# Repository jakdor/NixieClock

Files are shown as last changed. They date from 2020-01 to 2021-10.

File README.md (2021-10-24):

# Nixie clock firmware
### Firmware for IN12/IN14 nixie clock ATmega8 based design

For other PCB design checkout current branch:

| Design name | GIT branch |
| --- |:---:|
| IN-12 (THT) | IN12THT |
| IN-12 (SMD) | IN12SMD |
| IN-14 (SMD) | IN14SMD |

Compiling project
------

#### Windows

Download latest Atmel Studio IDE [Atmel Studio 7](https://www.microchip.com/mplab/avr-support/atmel-studio-7)

#### GNU/Linux (tested on Debian)

Makefile is located in Firmware/GccApplication2/ folder.

install dependencies:

```
make install
```

compile project:

```
make
```

flash ATmega using USBasp programmer:

```
make flash
```

PCB project
------

[PCB IN-12 Nixie clock](https://circuitmaker.com/Projects/Details/Jakub-Dorda/IN-12-Nixie-clock)

Output gerber files are located in 'PCBgerber' folder.

Compiled firmware
------

Download latest compiled firmware from GitHub repository release tab:

[Latest release](https://github.com/jakdor/NixieClock/releases)

Documentation/manuals
------

Documentation is located in 'Docs' folder or under this link:

[ASSEMBLY GUIDE/USER MANUAL/PARTS LIST](https://drive.google.com/drive/folders/0B9FzEUmQ64ufNGhZc0ZZaVdwLUU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)

FEATURES
------
* Full RGB backlight!
* Compact design
* HH:MM:SS format
* 24/12 h display format
* Alarm clock
* Backup power and settings memory
* Maintains time after power loss
* Backup battery lifetime up to 20 years
* accurate Real Time Clock
* Roulette Effect every hour (prevents cathode poisoning)
* Simple 3-buttons interface
* manual nixie brightness
* 3 separator modes (on, off, blinking)
* 6 RGB backlight modes including user defined and off
* night mode (turning off nixies and backlight between user set hours)

------

YouTube videos:

[https://www.youtube.com/watch?v=hwEY1RJ39X0](https://www.youtube.com/watch?v=hwEY1RJ39X0)

[https://www.youtube.com/watch?v=vacfdvKtQjE](https://www.youtube.com/watch?v=hwEY1RJ39X0)

NixieClock

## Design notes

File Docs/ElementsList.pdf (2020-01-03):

Designator | Value | Symbol | Quantity | Comment
Y1 | 32.768KHZ | - | 1
Y0 | 8Mhz | - | 1
X6-X9 | nixie IN-3 | - | 4 | or similar, can be modern neon
X0-X5 | nixie IN-12B | - | 6
VR0 | LM7805 | - | 1 | or similar 5V 1A linear stabilizer
U3 | K155NA1/SN74141N | - | 1 | available on eBay
U2 | NE555P | - | 1
U1 | DS1307 | - | 1
U0 | ATmega8A-PU | - | 1 | included with PCB
SW0-SW2 | 6mm switch | - | 3 | angular
R64-R69 | 15k | ████ | 6
R60-R63, R20 | 220k | ████ | 5
R42-R59 | 220 SMD 0805 | 220 | 18 | pre-soldered, value for 3000mcd LEDs
R35-R41 | 100k | ████ | 7
R28-R34 | 470k | ████ | 7
R18, R21-R27 | 33k | ████ | 8
R4-R6, R19 | 470 | ████ | 4
R1-R3, R15-R17 | 1k | ████ | 6
R0, R8-R14 | 10k | ████ | 8
Q14-Q20 | MPSA92 | - | 7 | or other PNP -300V -0.5A
Q7-Q13 | MPSA42 | - | 7 | or other NPN 300V 0.5A
Q6 | BC547BG | - | 1
Q5 | IRF730 | - | 1 | or other N-channel mosfet 2A
Q4 | 2N2907A | - | 1
Q1-Q3 | 2N3904TF | - | 3
P0 | 1k potentiometer | - | 1
L0 | 100uH | - | 1
J0 | 2.1/5.5mm 9v DC | - | 1
D3-D8 | LED 5mm RGB c. cathode | - | 6 | recommended min 3000mcd
D1 | UF4007 | - | 1 | super-fast <75ns 400V 1A
D0, D2 | 1N4007 | - | 2 | Rectifier diode 400V 1A
C16 | 2.2uF 400v | - | 1
C15 | 47pF | 47 | 1
C14 | 470uF | - | 1
C13 | 2.2nF | 222 | 1
C7-C8 | 22pF | 22 | 2
C2, C4-C6, C12 | 100nF | 104 | 5
C0, C1, C3 | 100uF | - | 3
BT0 | coincell CR2032 holder | - | 1
B0 | Buzzer Piezo 5v | - | 1 | with generator
Connector | M20 Vertical Pin Header | - | 21
Socket | Nixie pins | - | 72 | available on eBay

## Nixie pins can be skipped if you don't mount backlight LEDs

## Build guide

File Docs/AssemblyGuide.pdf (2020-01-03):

# ASSEMBLY GUIDE

# IN-12 NIXIE CLOCK v1.1

### Jakub Dorda © 2016-2017

2 | IN-12 Nixie Clock

### What You will need:

| • Soldering iron with standard and precise tip
- Side cutters
- Solder
| • Solder pump or solder wick (for correcting mistakes)

### Optional:

| • Pliers / small tongs / twisters
- Crocodile clip
- Multimeter

Estimated assembly time: 7-9h

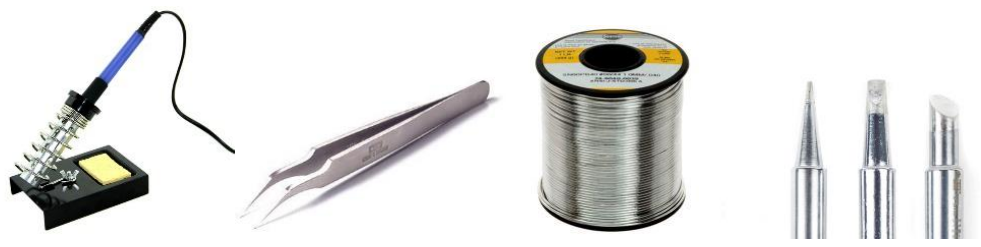
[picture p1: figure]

### Table of elements

Designator | Value | Symbol | Quantity
Y1 | 32.768KHZ | - | 1
Y0 | 8Mhz | - | 1
X6-X9 | nixie IN-3 | - | 4
X0-X5 | nixie IN-12B | - | 6
VR0 | LM7805 | - | 1
U3 | K155NA1/SN74141N | - | 1
U2 | NE555P | - | 1
U1 | DS1307 | - | 1

jak_dor | IN-12 Nixie Clock | 3
U0 | ATmega8A-PU | - | 1
SW0-SW2 | 6mm switch | - | 3
R64-R69 | 15k | ████ | 6
R60-R63, R20 | 220k | ████ | 5
R42-R59 | 220 SMD0805 | 220 | 18
R35-R41 | 100k | ████ | 7
R28-R34 | 470k | ████ | 7
R18, R21-R27 | 33k | ████ | 8
R4-R7, R19 | 470 | ████ | 5
R1-R3, R15-R17 | 1k | ████ | 6
R0, R8-R14 | 10k | ████ | 8
Q14-Q20 | MPSA92 | KSP 92 | 7
Q7-Q13 | MPSA42 | A 42 | 7
Q6 | BC547BG | - | 1
Q5 | IRF730 | - | 1
Q4 | 2N2907A | - | 1
Q0-Q3 | 2N3904TF | - | 4
P0 | 1k potentiometer | - | 1
L0 | 100uH | - | 1
J0 | 2.1/5.5mm 9v DC | - | 1
D3-D8 | LED 5mm RGB | - | 6
D1 | UF4007 | - | 1
D0, D2 | 1N4007 | - | 2
C16 | 2.2uF | - | 1
C15 | 47pF | 47 | 1
C14 | 470uF | - | 1
C13 | 2.2nF | 222 | 1
C7-C8 | 22pF | 22 | 2
C2, C4-C6, C12 | 100nF | 104 | 5
C0, C1, C3 | 100uF | - | 3
BT0 | coincell CR2032 holder | - | 1
B0 | Buzzer Piezo 5v | - | 1
Connector | M20 Vertical Pin Header | - | 21

### 1. SMD elements

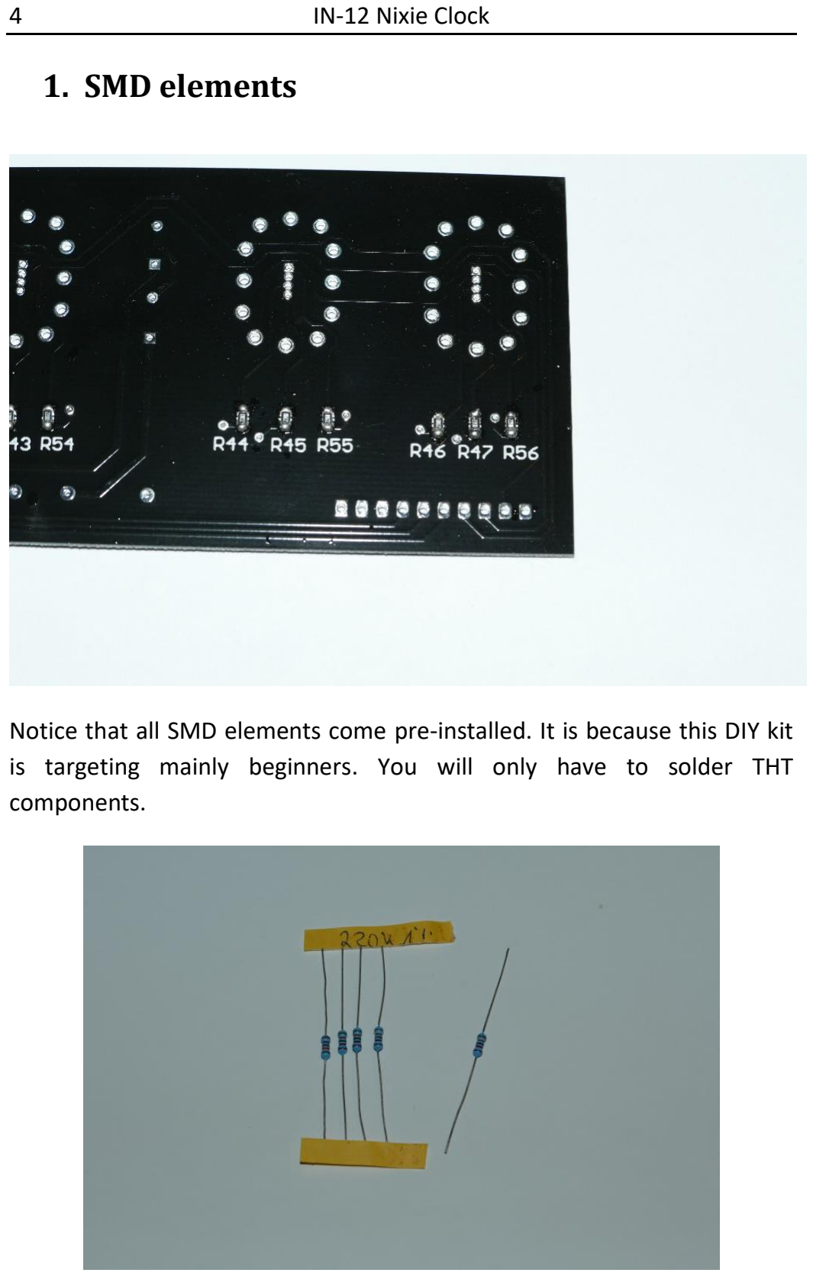
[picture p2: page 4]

Notice that all SMD elements come pre-installed. It is because this DIY kit is targeting mainly beginners. You will only have to solder THT components.

### 2. Resistors

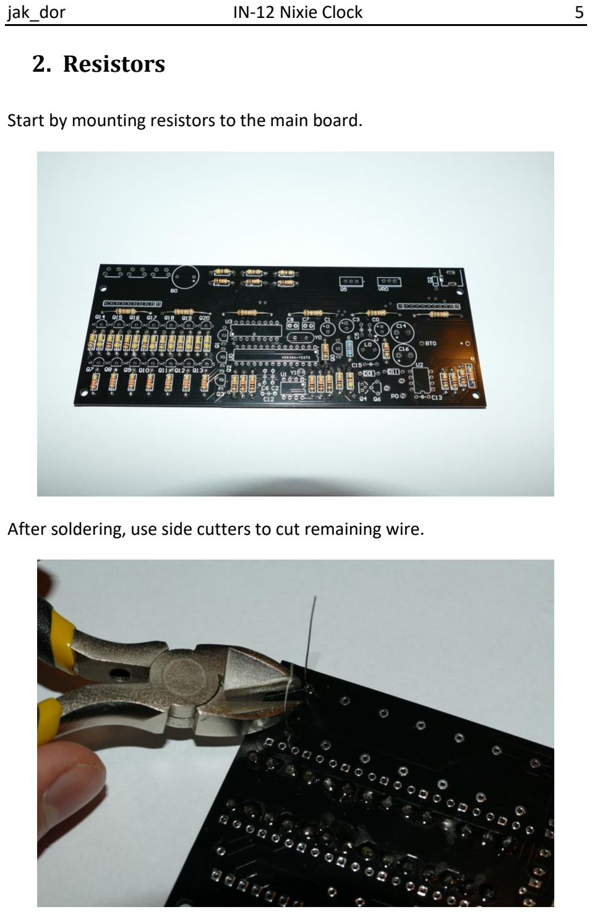
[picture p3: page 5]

Start by mounting resistors to the main board.

After soldering, use side cutters to cut remaining wire.

### 3. Rectifier diodes

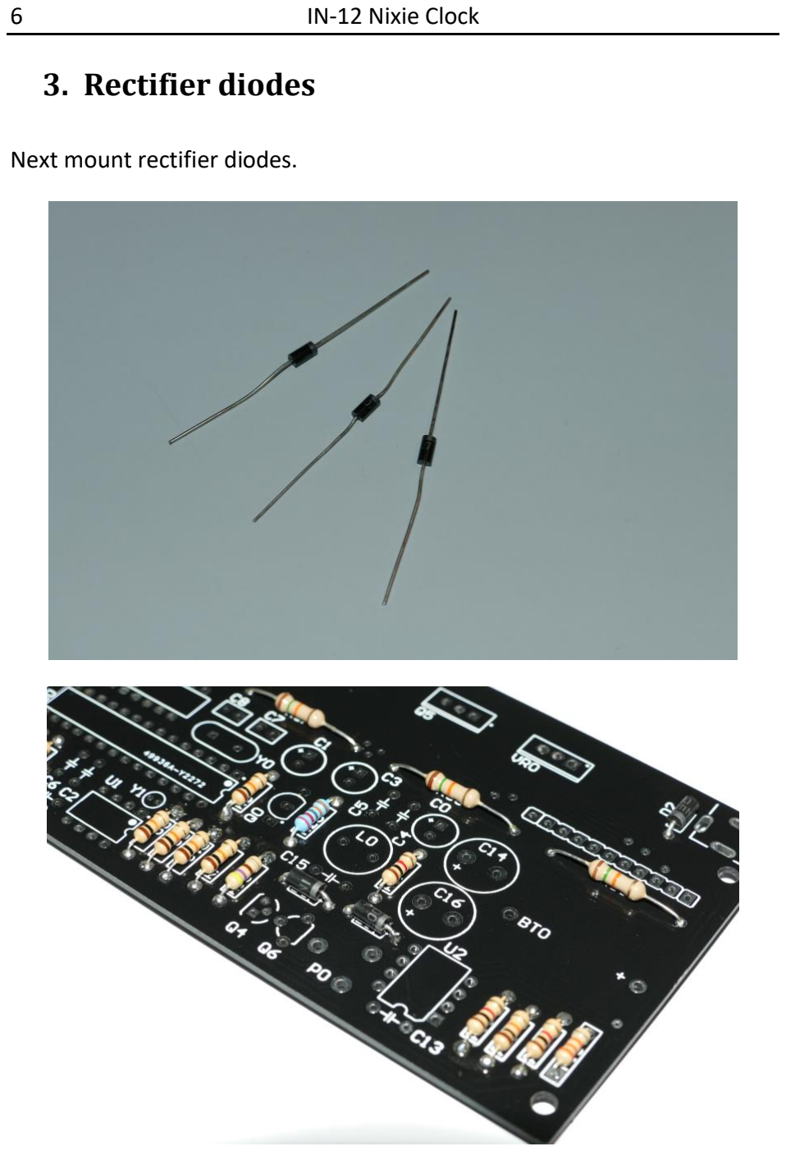
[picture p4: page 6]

Next mount rectifier diodes.

### 4. Integrated circuits sockets

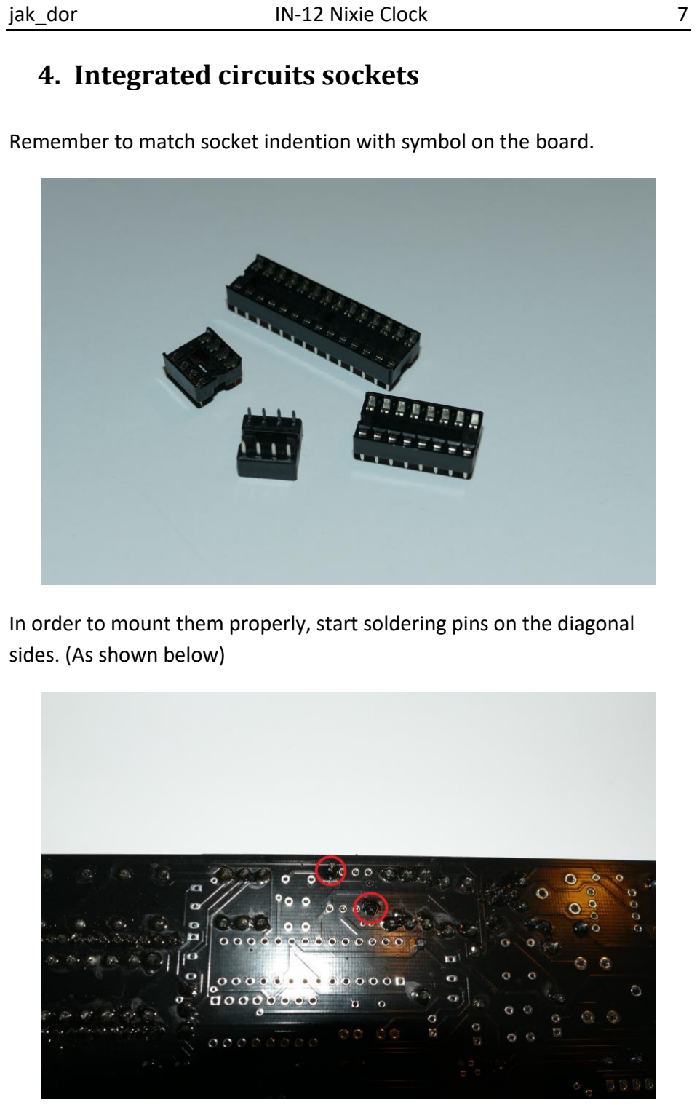
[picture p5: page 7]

Remember to match socket indention with symbol on the board.

In order to mount them properly, start soldering pins on the diagonal sides. (As shown below)

### 5. Transistors

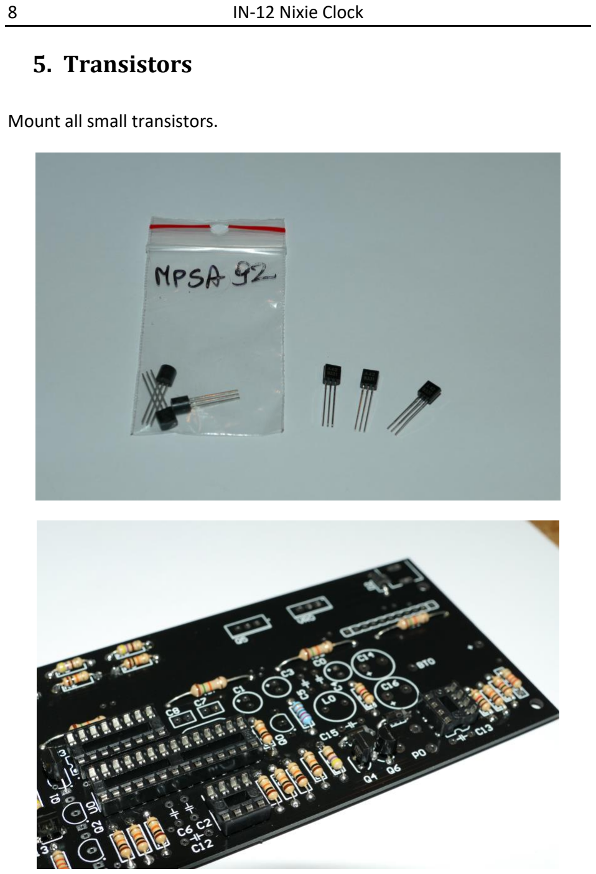
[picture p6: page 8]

Mount all small transistors.

### 6. Ceramic capacitors

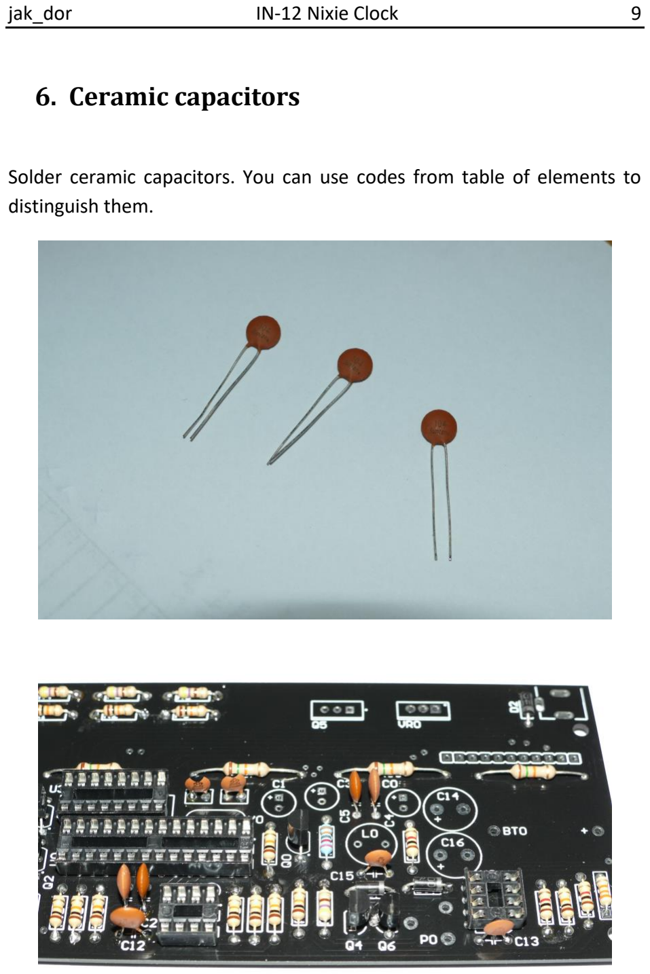
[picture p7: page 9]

Solder ceramic capacitors. You can use codes from table of elements to distinguish them.

### 7. Crystals

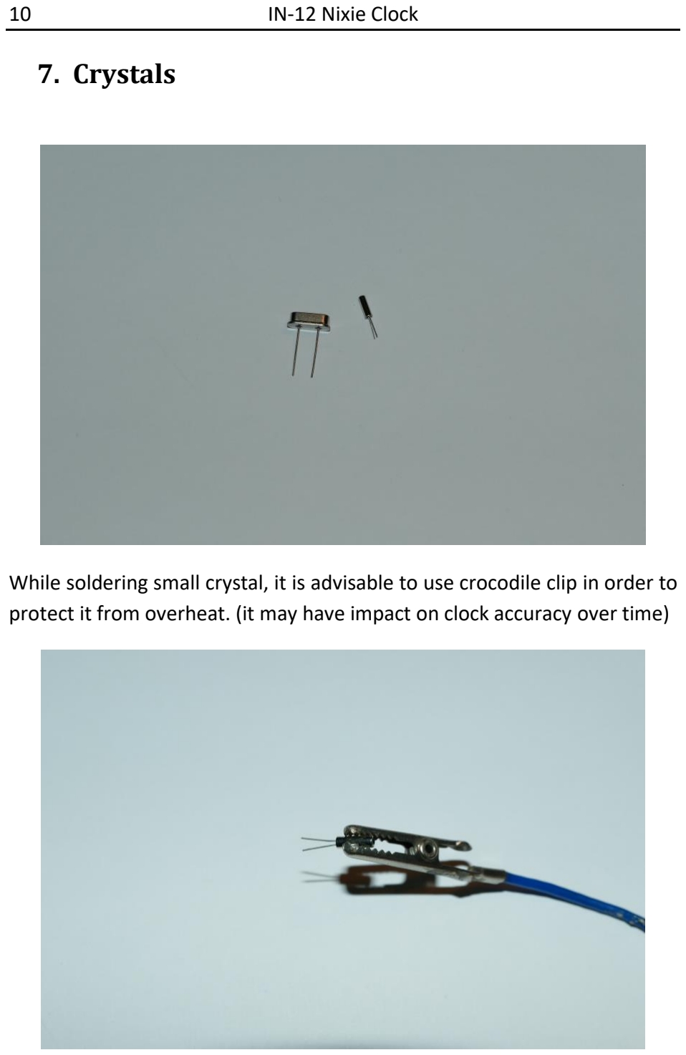
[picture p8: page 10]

While soldering small crystal, it is advisable to use crocodile clip in order to protect it from overheat. (it may have impact on clock accuracy over time)

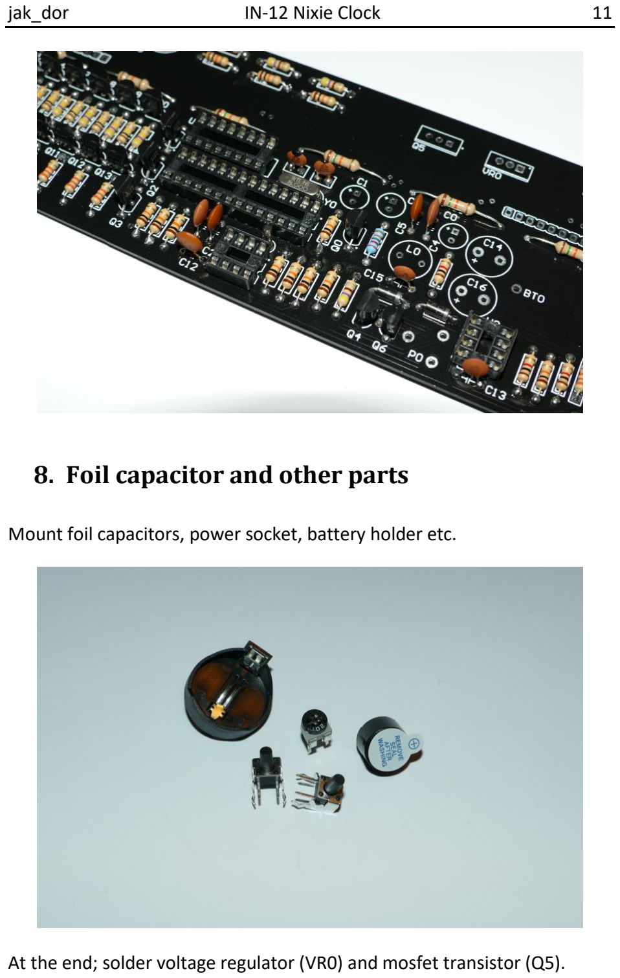
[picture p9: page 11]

### 8. Foil capacitor and other parts

Mount foil capacitors, power socket, battery holder etc.

At the end; solder voltage regulator (VR0) and mosfet transistor (Q5).

### 9. Miscellaneous elements on the display board

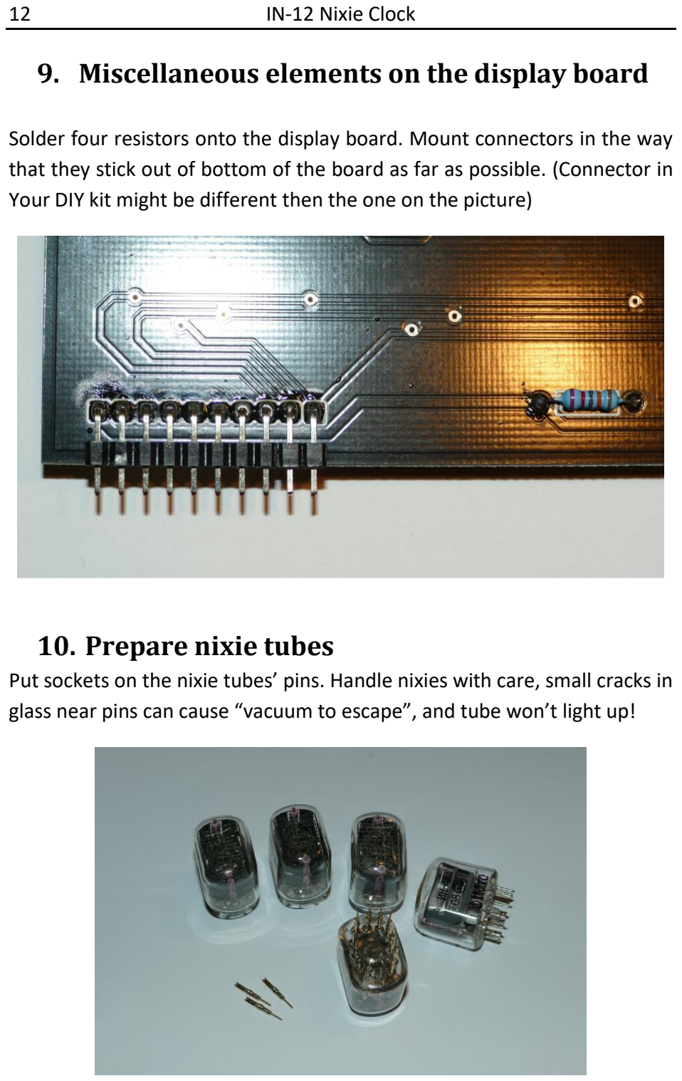
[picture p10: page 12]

Solder four resistors onto the display board. Mount connectors in the way that they stick out of bottom of the board as far as possible. (Connector in Your DIY kit might be different then the one on the picture)

### 10. Prepare nixie tubes

Put sockets on the nixie tubes’ pins. Handle nixies with care, small cracks in glass near pins can cause “vacuum to escape”, and tube won’t light up!

### 11. Solder nixie tubes’ sockets

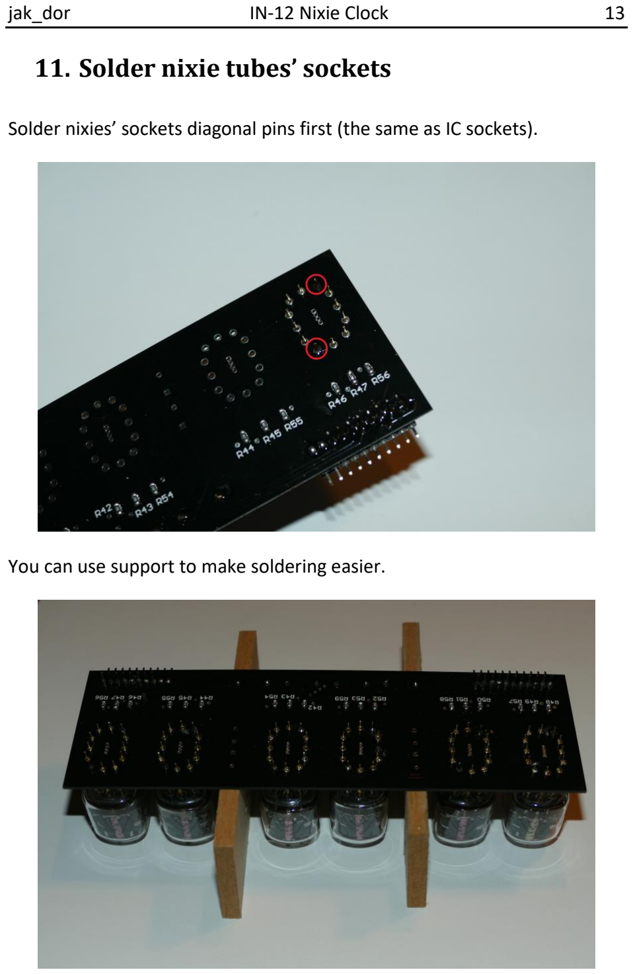
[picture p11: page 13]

Solder nixies’ sockets diagonal pins first (the same as IC sockets).

You can use support to make soldering easier.

### 12. Remove nixies from sockets

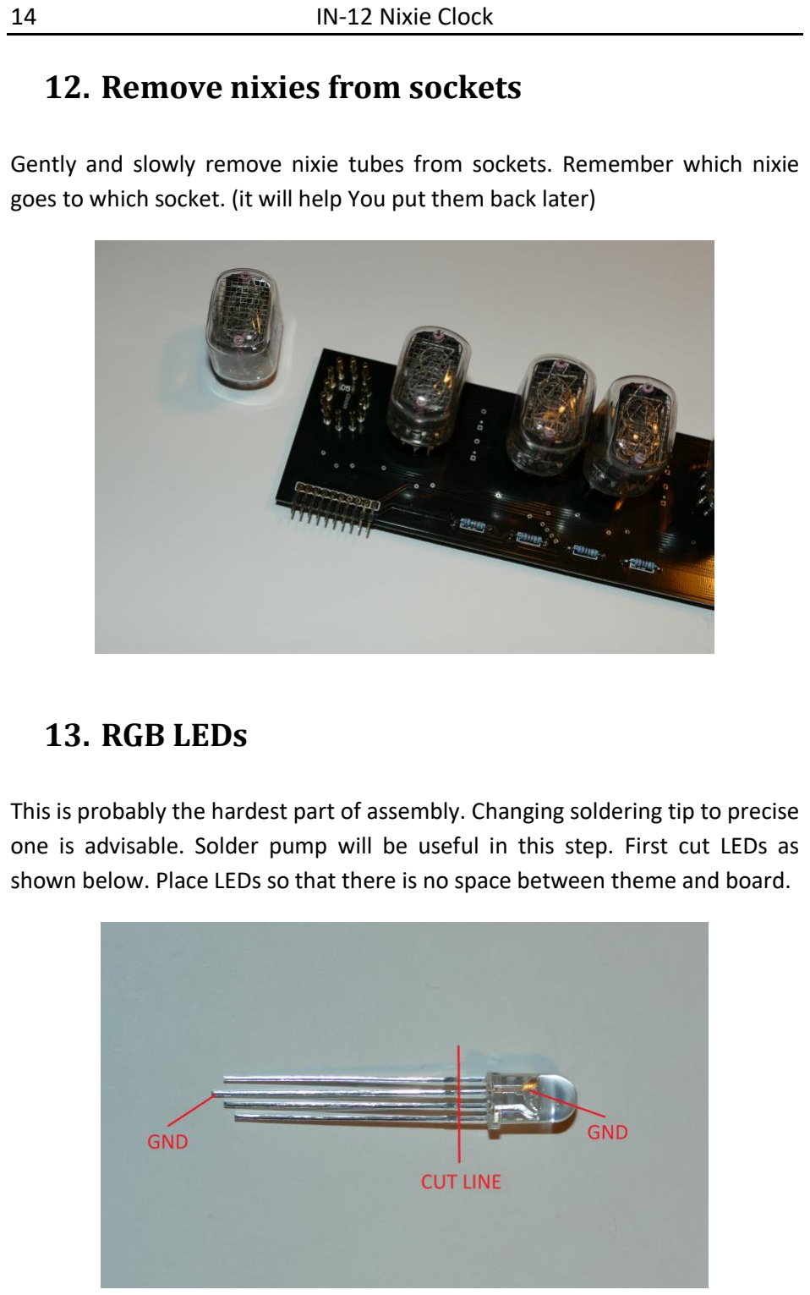
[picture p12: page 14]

Gently and slowly remove nixie tubes from sockets. Remember which nixie goes to which socket. (it will help You put them back later)

### 13. RGB LEDs

This is probably the hardest part of assembly. Changing soldering tip to precise one is advisable. Solder pump will be useful in this step. First cut LEDs as shown below. Place LEDs so that there is no space between theme and board.

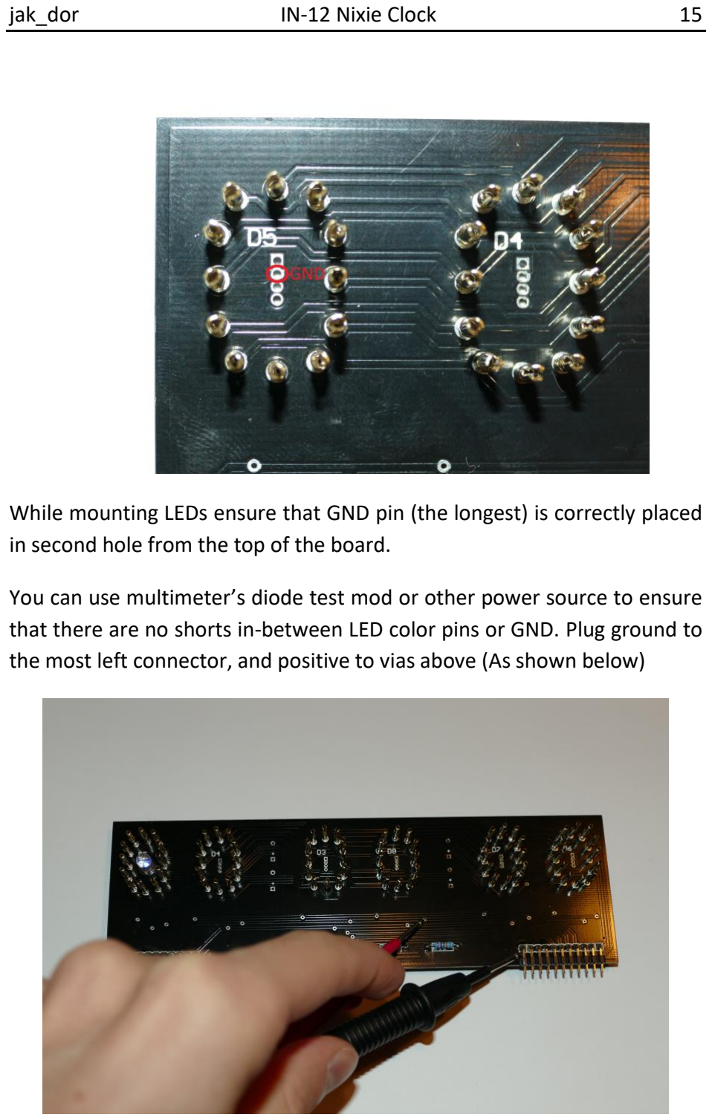
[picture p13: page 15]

While mounting LEDs ensure that GND pin (the longest) is correctly placed in second hole from the top of the board.

You can use multimeter’s diode test mod or other power source to ensure that there are no shorts in-between LED color pins or GND. Plug ground to the most left connector, and positive to vias above (As shown below)

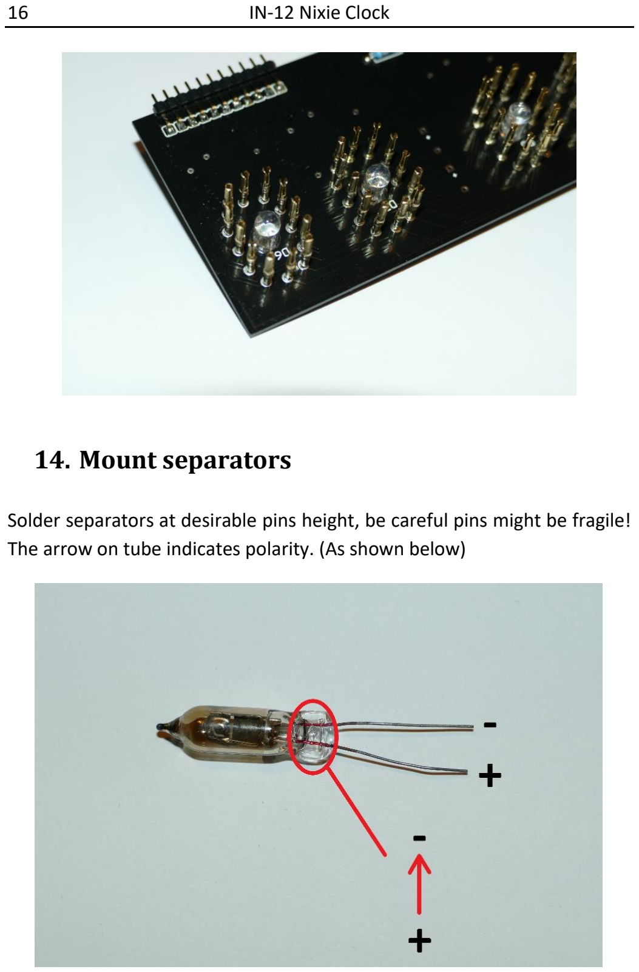
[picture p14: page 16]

### 14. Mount separators

Solder separators at desirable pins height, be careful pins might be fragile! The arrow on tube indicates polarity. (As shown below)

### 15. Place nixie tubes back in their sockets

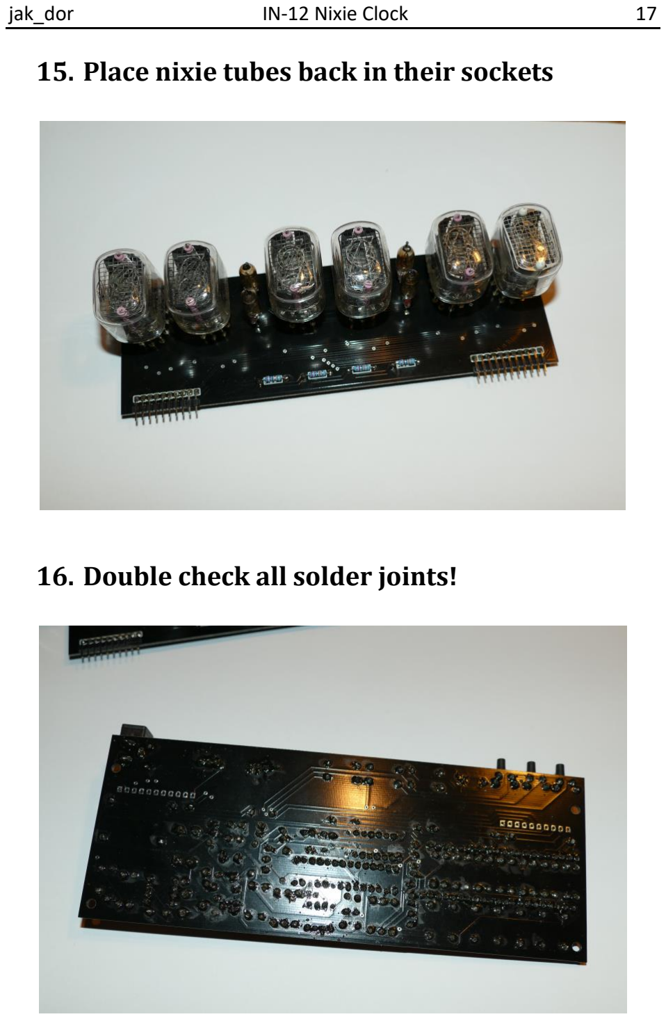
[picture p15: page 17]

### 16. Double check all solder joints!

### 17. Place IC in their sockets

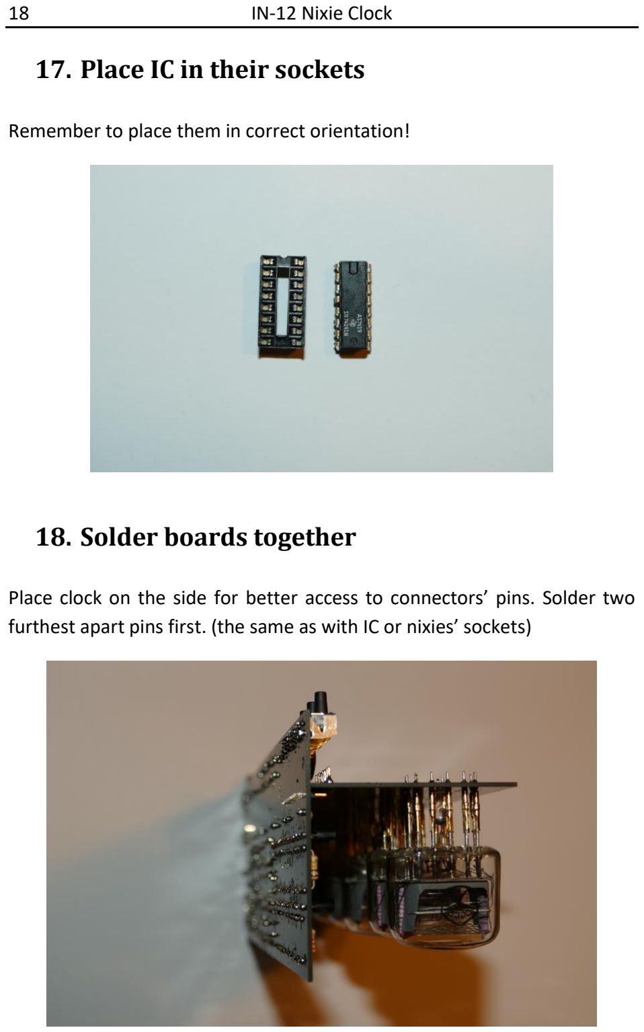
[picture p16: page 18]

Remember to place them in correct orientation!

### 18. Solder boards together

Place clock on the side for better access to connectors’ pins. Solder two furthest apart pins first. (the same as with IC or nixies’ sockets)

### 19. Turn on

After last step, the clock should be completed. Just insert battery (will not boot up without it!), plug the power supply and You are ready to go!

Don’t forget to set up time first and adjust brightness. You will find instruction how to do that in the User Manual.

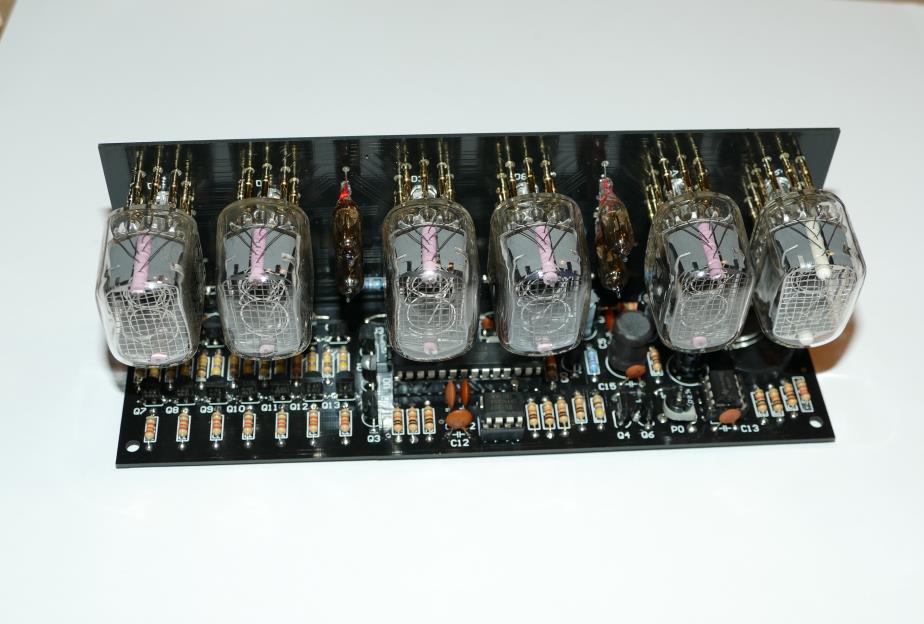
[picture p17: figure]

I hope everything went as planned, and Your nixie clock is working flawlessly and it will serve You for many years to come!

Sincerely, Jakub Dorda

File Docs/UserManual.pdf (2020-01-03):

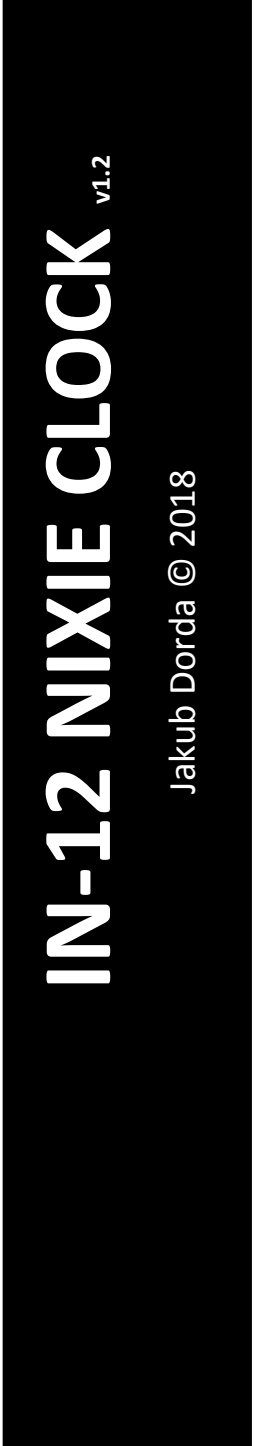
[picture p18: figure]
IN-12 NIXIE CLOCK v1.2; Jakub Dorda © 2018

# USER MANUAL

2 | IN-12 Nixie Clock

## Table of contents

jak_dor | IN-12 Nixie Clock | 3

### Introduction

Thank You for choosing this nixie clock, I sincerely hope that owning and using it will give You as much fun and satisfaction as designing it gave me. If You have any questions or encountered unpredicted problem; contact me through this e-mail address: jak_dor@wp.pl or eBay message.

| | Sincerely, Jakub Dorda

### High voltage warning

Nixie tubes require high voltage to operate, therefore this nixie clock has some parts of its circuitry that run voltage around 180-300V DC. Do not touch any electric circuit during operation!

### Power supply

This device requires 9V DC constant voltage power source with at least 400mA load capability. Power plug must have 2.1/5.5 standard with center positive polarity; (-) outside barrel (+) inside tip. It is advisable to use good quality stabilized or pulse power based supply.

### First use

Insert DC power plug first then plug power supply into electrical outlet. Clock should start operating right away. If display is showing 00:00:80 it is sign that time was never set or backup battery was replaced. In order to fix it look up how to set up time (page 5).

## Settings and usage

Buttons description
Buttons are named by their position while looking at the clock from the front
Left | – down / change display format
Middle | – settings / next field
Right | – up / alarm on & off

Changing display format
While clock is displaying time, press | Left | button to switch between 12h and
24h display format.

Alarm on & off
While clock is displaying time, press Right button to turn alarm on and off. Setting alarm on is indicated by three beeps. Setting alarm off is indicated by one beep lasting 2 seconds.

Settings’ mode

In order to enter settings’ mode, click Middle. First two digits represents menu page and next four nixies displays values in two fields that you can modify. Field that you are currently modifying will blink.

If you press | Right | while first two digits blink, you will move forward to next
setting page. By pressing | Middle, you can change active field to the next
one, and modify it with Right and Left buttons.
After moving through all three fields next press of | Middle | button will save
changes and return to normal operation mode.

## Setting pages’ description

### 1. Time setting

First page in settings’ mode allows for modifying current time which clock will display. Notice that although clock has 12/24h display format in order to avoid confusion settings’ mode uses 24h display format only! Sorry for inconvenience.

### 2. Alarm setting

This page allows to set alarm time. After changing value in this page alarm clock is automatically turned on. (How to turn alarm on and off on page 4)

### 3. Night mode start

Night mode allows to turn off nixies and backlight on set time. This allows for increased nixies life span and turning off light source If you sleep in the same room where clock is placed.

During night mode, you can still enter settings’ mode, however setting pages 5 and 6 are not available.

### 4. Night mode end

Setts time after which clock will turn nixies and backlight back on after night mode.

If you don’t want to use night mode set both night mode start and end to the same time. For instance; set both to 00:00.

### 5. Separator and backlight settings

First field allows to modify separators behavior:

0 – turned off
1 – blinking
2 – constantly on

Second field modify backlight behavior:

0 – turned off
1 – changing random RGB color (every 1.5min)
2 – changing base color (red, green, blue) (every 1.5min) 3 – changing random RGB color (every 1h)
4 – changing base color (red, green, blue) (every 1h)
5 – user defined color

Setting 5 without specifying your own color at setting page 6 will save currently displayed color.

### 6. User defined RGB color

This page unlike rest of them doesn’t have first field dedicated to displaying setting page. All three fields represent each base color (red, green, blue). As you modify values backlight will change accordingly. Any change in this page will result in setting mode 5 in backlight behavior automatically.

### Setting nixies’ brightness

First unplug power supply from electrical outlet. Use small slotted or philips screwdriver and gently turn trim pod located in front right part of main board. Turn clock back on to check on results, repeat process until you are satisfied with nixies’ brightness.

### Increasing nixies’ life span

It is advisable not to set brightness too high as it may cause nixies to age faster. Using night mode for couple hours every day will help as well. Don’t forget that clock has backup power so if you are away from home for longer than a day, feel free to turn it off, all settings and time will be saved.

### Anticathode poisoning

Cathode poisoning is happening when nixie tube is turned too long on same digit, therefore setting separators on setting 2 (constantly on) is not advisable.

This clock also has special system that prevents cathode poisoning by “roulette effect” which is happening every hour for 10 seconds.

### Replacing nixie tube

If one of nixie tubes happens to break down or cathode poisoning becomes to apparent, it is probably sign that you should replace it with “new” one.

First unplug power supply, hold display board with one hand, as you gently wobble nixie tube up and down while pulling it towards you. Be careful not to damage sockets. After removing faulty nixie, proceed by inserting new one again by wobbling it carefully as you push it in.

### Troubleshooting

### Clock doesn’t turn on after assembly

If you bought this clock as DIY kit, and it’s not working at all, double check that you didn’t make any mistake during assembly or insert backup battery.

Clock doesn’t turn on but it was working already
Check if clock is not in night mode by pressing Middle. Check if power supply is working correctly.

Clock display acting weirdly
It might be sign that nixie driver (IN74141 or K155ID1) broke down, replace it with new one.

Contact: jak_dor@wp.pl or eBay message

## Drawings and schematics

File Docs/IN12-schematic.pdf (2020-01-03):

1

2

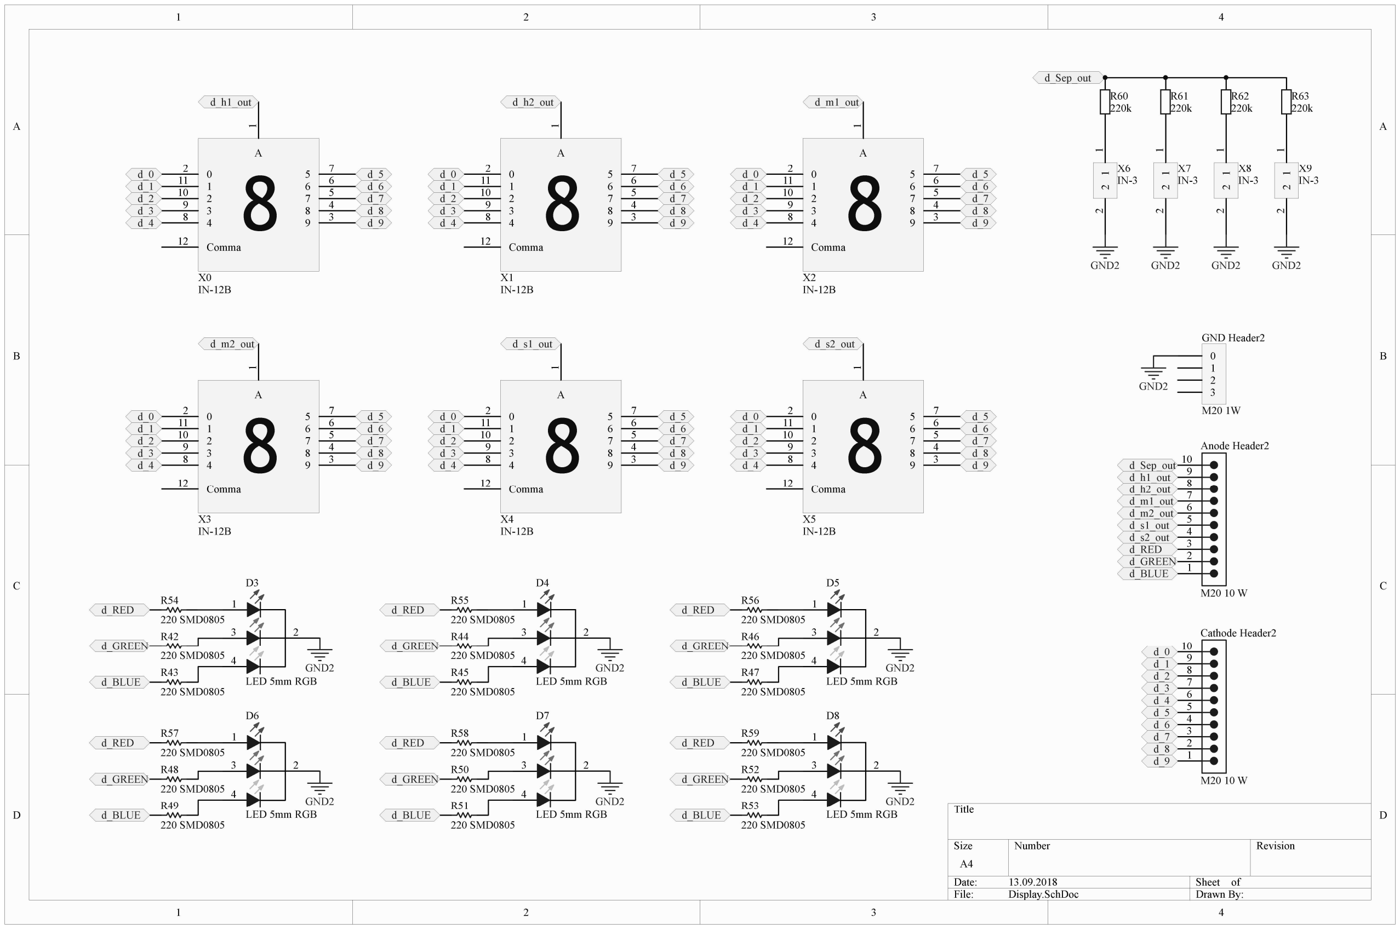
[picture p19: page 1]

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
### Title

Size | Number | Revision
A4
Date: | 13.09.2018 | Sheet of
File: | Display.SchDoc | Drawn By:

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
10 1

11

Comma 12 | 8

X5

### IN-12B

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
10 1

11

Comma 12 | 8

X1

### IN-12B

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
10 1

11

Comma 12 | 8

X3

### IN-12B

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
10 1

11

Comma 12 | 8

X4

### IN-12B

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
10 1

11

Comma 12 | 8

X0

### IN-12B

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
10 1

11

Comma 12 | 8

X2

### IN-12B

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
### Cathode Header2

M20 10 W

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
### Anode Header2

M20 10 W

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
### d_Sep_out d_h1_out d_h2_out d_m1_out d_m2_out d_s1_out d_s2_out

d_h1_out | d_h2_out | d_m1_out
d_m2_out | d_s1_out | d_s2_out

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
### 220 SMD0805

0
1
2
3

### GND Header2

M20 1W

### d_RED d_GREEN d_BLUE

R54

### 220 SMD0805

R42

### 220 SMD0805

1

3

4

2

D3

### LED 5mm RGB

### GND2

### d_RED

### d_GREEN

### d_BLUE

R45

### 220 SMD0805

R55

### 220 SMD0805

R44

### 220 SMD0805

1

3

4

2

D4

### LED 5mm RGB

GND2 | R47
| 220 SMD0805

R56

### 220 SMD0805

R46

### 220 SMD0805

1

3

4

2

D5

### LED 5mm RGB

### GND2

R49

### 220 SMD0805

R57

### 220 SMD0805

R48

### 220 SMD0805

1

3

4

2

D6

### LED 5mm RGB

GND2 | R51
| 220 SMD0805

R58

### 220 SMD0805

R50

### 220 SMD0805

1

3

4

2

D7

### LED 5mm RGB

GND2 | R53
| 220 SMD0805

R59

### 220 SMD0805

R52

### 220 SMD0805

1

3

4

2

D8

### LED 5mm RGB

### GND2

1

1

2

2

X6
IN-3 | 1
| 1

2

2

X7
IN-3 | 1
| 1

2

2

X8
IN-3 | 1
| 1

2

2

X9
IN-3

R60
220k

R61
220k

R62
220k

R63
220k

### d_Sep_out

### d_RED

### d_GREEN

### d_BLUE

### d_RED

### d_GREEN

### d_BLUE

### d_RED

### d_GREEN

### d_BLUE

### d_RED

### d_GREEN

### d_BLUE

### d_RED

### d_GREEN

### d_BLUE

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
### GND2

GND2 | GND2 | GND2 | GND2

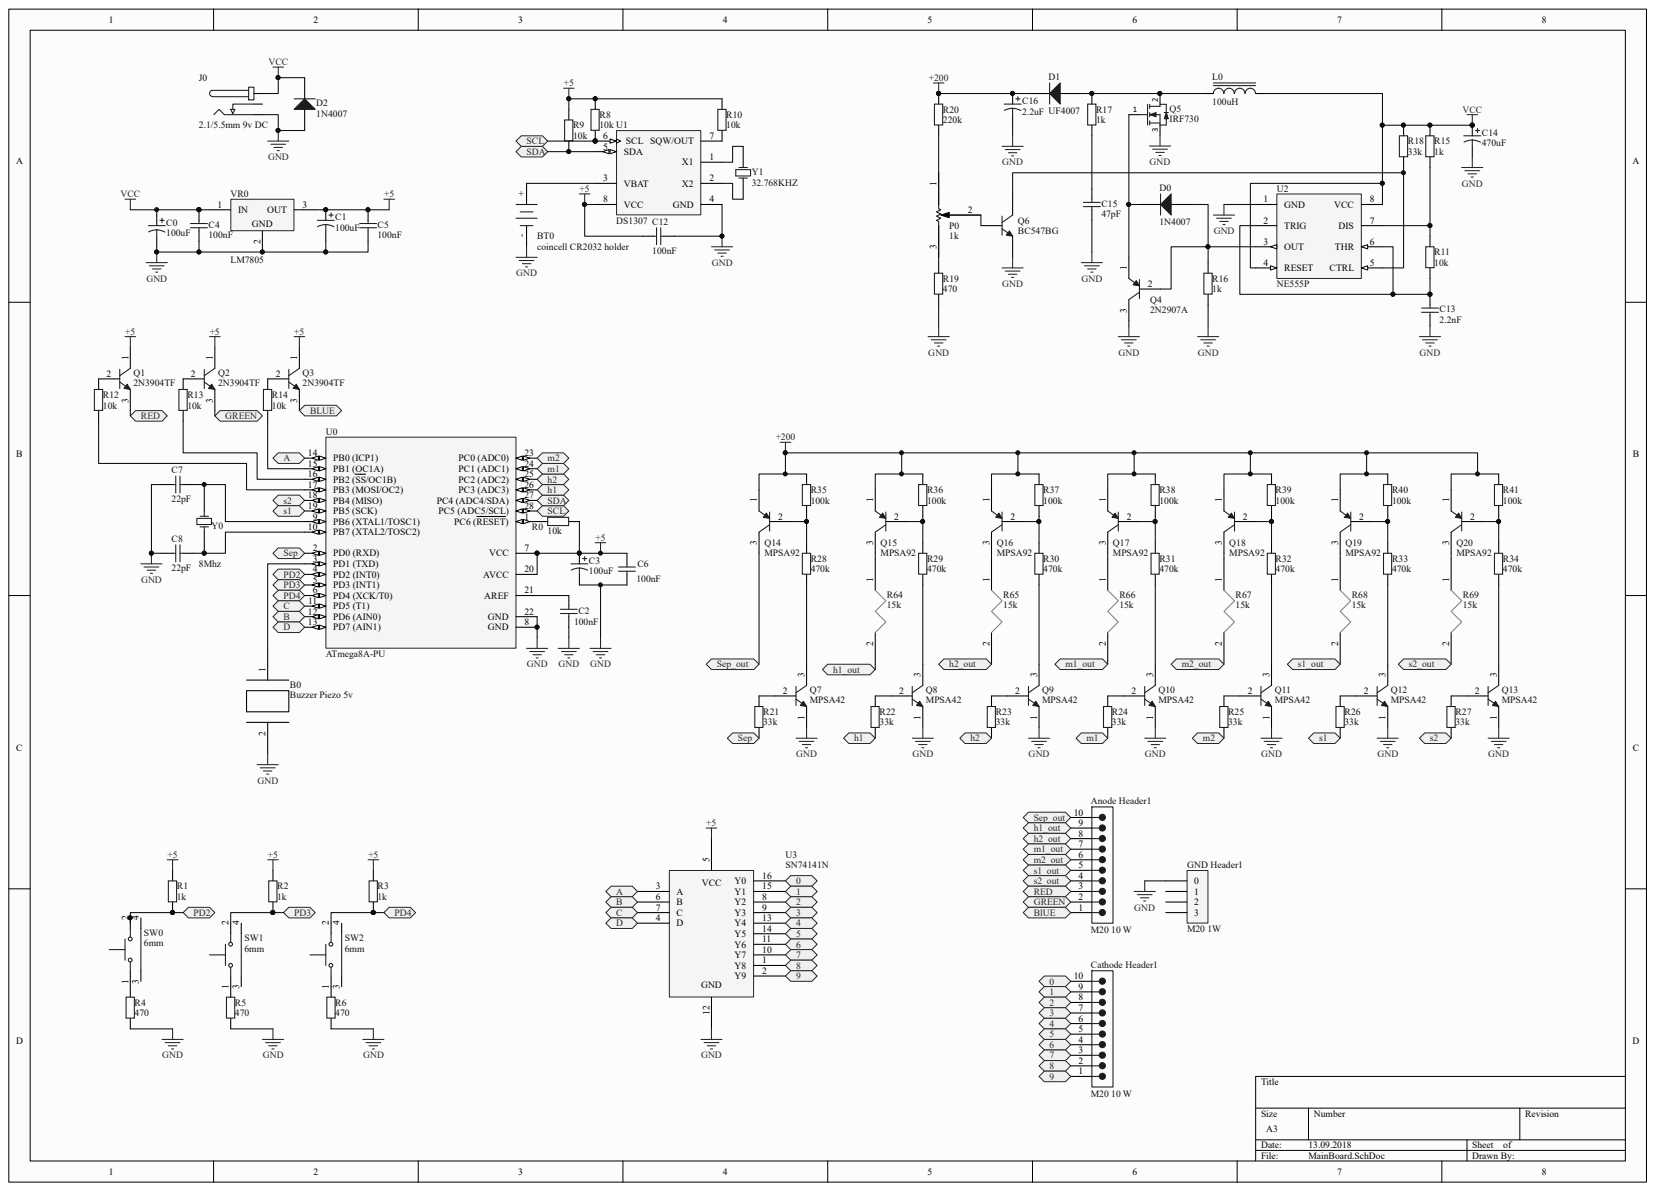
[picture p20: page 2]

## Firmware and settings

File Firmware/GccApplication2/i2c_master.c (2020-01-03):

#ifndef  F_CPU
#define F_CPU 8000000UL
#endif

#include <avr/io.h>
#include <util/twi.h>

#include "i2c_master.h"

#define F_SCL 100000UL // SCL frequency
#define Prescaler 1
#define TWBR_val ((((F_CPU / F_SCL) / Prescaler) - 8 ) / 2)

void i2c_init(void)
{
	TWBR = (uint8_t)TWBR_val;
}

uint8_t i2c_start(uint8_t address)
{
	// reset TWI control register
	TWCR = 0;
	// transmit START condition 
	TWCR = (1<<TWINT) | (1<<TWSTA) | (1<<TWEN);
	// wait for end of transmission
	while( !(TWCR & (1<<TWINT)) );
	
	// check if the start condition was successfully transmitted
	if((TWSR & 0xF8) != TW_START){ return 1; }
	
	// load slave address into data register
	TWDR = address;
	// start transmission of address
	TWCR = (1<<TWINT) | (1<<TWEN);
	// wait for end of transmission
	while( !(TWCR & (1<<TWINT)) );
	
	// check if the device has acknowledged the READ / WRITE mode
	uint8_t twst = TW_STATUS & 0xF8;
	if ( (twst != TW_MT_SLA_ACK) && (twst != TW_MR_SLA_ACK) ) return 1;
	
	return 0;
}

uint8_t i2c_write(uint8_t data)
{
	// load data into data register
	TWDR = data;
	// start transmission of data
	TWCR = (1<<TWINT) | (1<<TWEN);
	// wait for end of transmission
	while( !(TWCR & (1<<TWINT)) );
	
	if( (TWSR & 0xF8) != TW_MT_DATA_ACK ){ return 1; }
	
	return 0;
}

uint8_t i2c_read_ack(void)
{
	// start TWI module and acknowledge data after reception
	TWCR = (1<<TWINT) | (1<<TWEN) | (1<<TWEA); 
	// wait for end of transmission
	while( !(TWCR & (1<<TWINT)) );
	// return received data from TWDR
	return TWDR;
}

uint8_t i2c_read_nack(void)
{
	// start receiving without acknowledging reception
	TWCR = (1<<TWINT) | (1<<TWEN);
	// wait for end of transmission
	while( !(TWCR & (1<<TWINT)) );
	// return received data from TWDR
	return TWDR;
}

uint8_t i2c_transmit(uint8_t address, uint8_t* data, uint16_t length)
{
	if (i2c_start(address | I2C_WRITE)) return 1;
	
	for (uint16_t i = 0; i < length; i++)
	{
		if (i2c_write(data[i])) return 1;
	}
	
	i2c_stop();
	
	return 0;
}

uint8_t i2c_receive(uint8_t address, uint8_t* data, uint16_t length)
{
	if (i2c_start(address | I2C_READ)) return 1;
	
	for (uint16_t i = 0; i < (length-1); i++)
	{
		data[i] = i2c_read_ack();
	}
	data[(length-1)] = i2c_read_nack();
	
	i2c_stop();
	
	return 0;
}

uint8_t i2c_writeReg(uint8_t devaddr, uint8_t regaddr, uint8_t* data, uint16_t length)
{
	if (i2c_start(devaddr | 0x00)) return 1;

	i2c_write(regaddr);

	for (uint16_t i = 0; i < length; i++)
	{
		if (i2c_write(data[i])) return 1;
	}

	i2c_stop();

	return 0;
}

uint8_t i2c_readReg(uint8_t devaddr, uint8_t regaddr, uint8_t* data, uint16_t length)
{
	if (i2c_start(devaddr)) return 1;

	i2c_write(regaddr);

	if (i2c_start(devaddr | 0x01)) return 1;

	for (uint16_t i = 0; i < (length-1); i++)
	{
		data[i] = i2c_read_ack();
	}
	data[(length-1)] = i2c_read_nack();

	i2c_stop();

	return 0;
}

void i2c_stop(void)
{
	// transmit STOP condition
	TWCR = (1<<TWINT) | (1<<TWEN) | (1<<TWSTO);
}
